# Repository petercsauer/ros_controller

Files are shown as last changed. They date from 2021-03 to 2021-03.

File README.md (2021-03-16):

# ros_controller

## Project Description
The ROS Controller was created as a part of a MSR @ Northwestern winter project. The goal was to create a controller that can be easily customized to help ROS developers debug new applications and help regular robot technicians program new capabilities into existing applications. Please see https://petercsauer.github.io/controller.html for more information.

## Usage Instructions
- Connect the robot and controller to the same network
- export ROS_HOSTNAME=http://raspberrypi.local:11311 (on robot)
- export ROS_IP=raspberrypi.local (on robot)
- roslaunch control control.launch (on controller)
- run any node to be tested on the robot

## Software
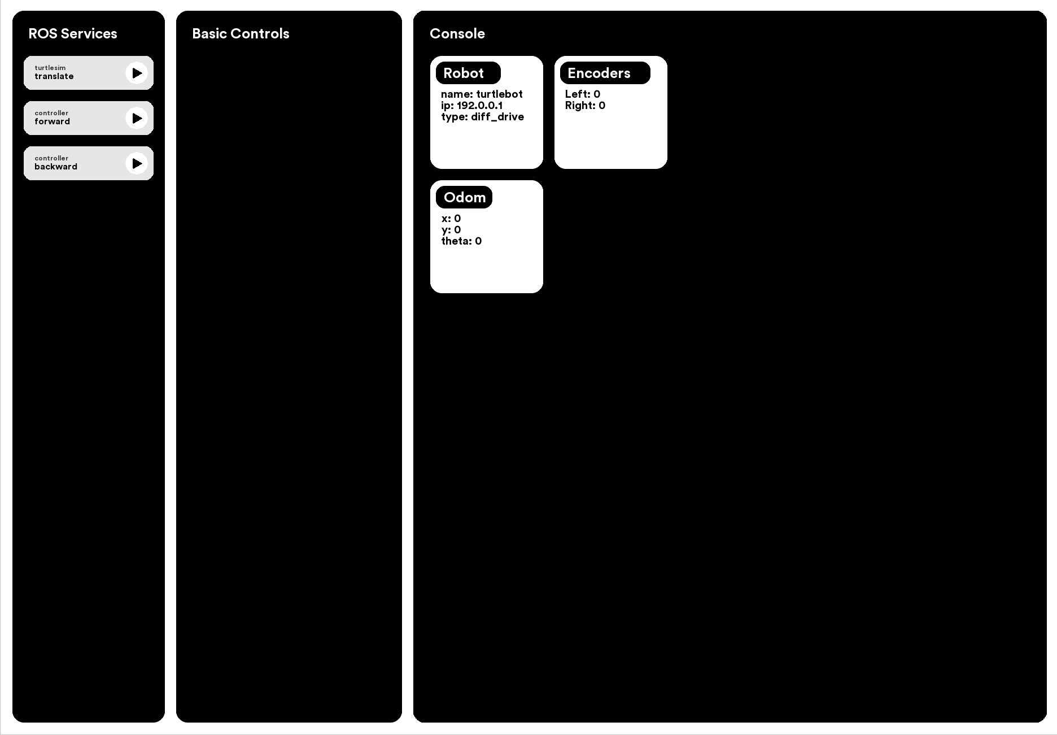
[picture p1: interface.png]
Interface

### Modes of Usage
##### Mouse Control Mode
- In this mode, the left joystick controls the mouse on the raspberry pi in the controller. 
- This can be useful to select functions and run programs on raspberry OS.
- Can switch between mouse control and velocity control modes by holding down the joystick button for 2 seconds.
- Video Demo: https://drive.google.com/file/d/1apWOIeSkuBDc_xTBUmET32rqAUC1X6jY/view?usp=sharing

##### Joystick Control Mode 
- In this mode, the left joystick controls the menu selection options in the interface
- This can be used to press the menu buttons in the application and run services or remote options.
- Can switch between joystick control and velocity control modes by holding down the joystick button for 2 seconds.

##### Velocity Control Mode
- In this mode, the left joystick sends cmd_vel commands to any connected robot
- This can be useful to drive around a diff drive style of robot.
- In this mode, movement left to right publishes to twist.angular.z and up and down movement publishes to twist.linear.x
- Video Demo: https://drive.google.com/file/d/1Vq2hrRpSAihLlSR3H_R1zQseN4hwDoo5/view?usp=sharing

##### Mouse and Keyboard Control
- The controller comes with a wireless mouse and keyboard attatched, so the developer can utilize all of the raspbian os.
- In this mode, the controller becomes a full linux computer, using the eink display as a full display.
- Video Demo: https://drive.google.com/file/d/1e-eE9lNR6LbbHdcuiJWl0FAsSrEUFRB0/view?usp=sharing

##### Info Modules
- Info modules have been created to allow the developer to easily display useful data from the robot.
- In this example, the robots pose, and encoder data is published here as well as some useful data about the robot.
- Video Demo: https://drive.google.com/file/d/1NOoGeiinw6MxqIVGJ60zSW3B7ncj2-ec/view?usp=sharing

##### Service Modules
- Service modules have been created to allow the developer to easily test different services offered by the robot.
- Developers can click the play button next to a service option to run that service with an autocompleted command (\t).
- Developers can click the main section of the service module to input their own command to run.

### Configurability
##### Info Modules
- Info modules can be configured in the modules.yaml file. 
- Info modules can be removed or added depending on the setting in that file and the usage case of the developer

##### Basic Remote
- Action buttons can also be added through the modules.yaml file.
- Each button has a publisher associated with it, and can publish a specific message which is configured by the developer in the modules.yaml file

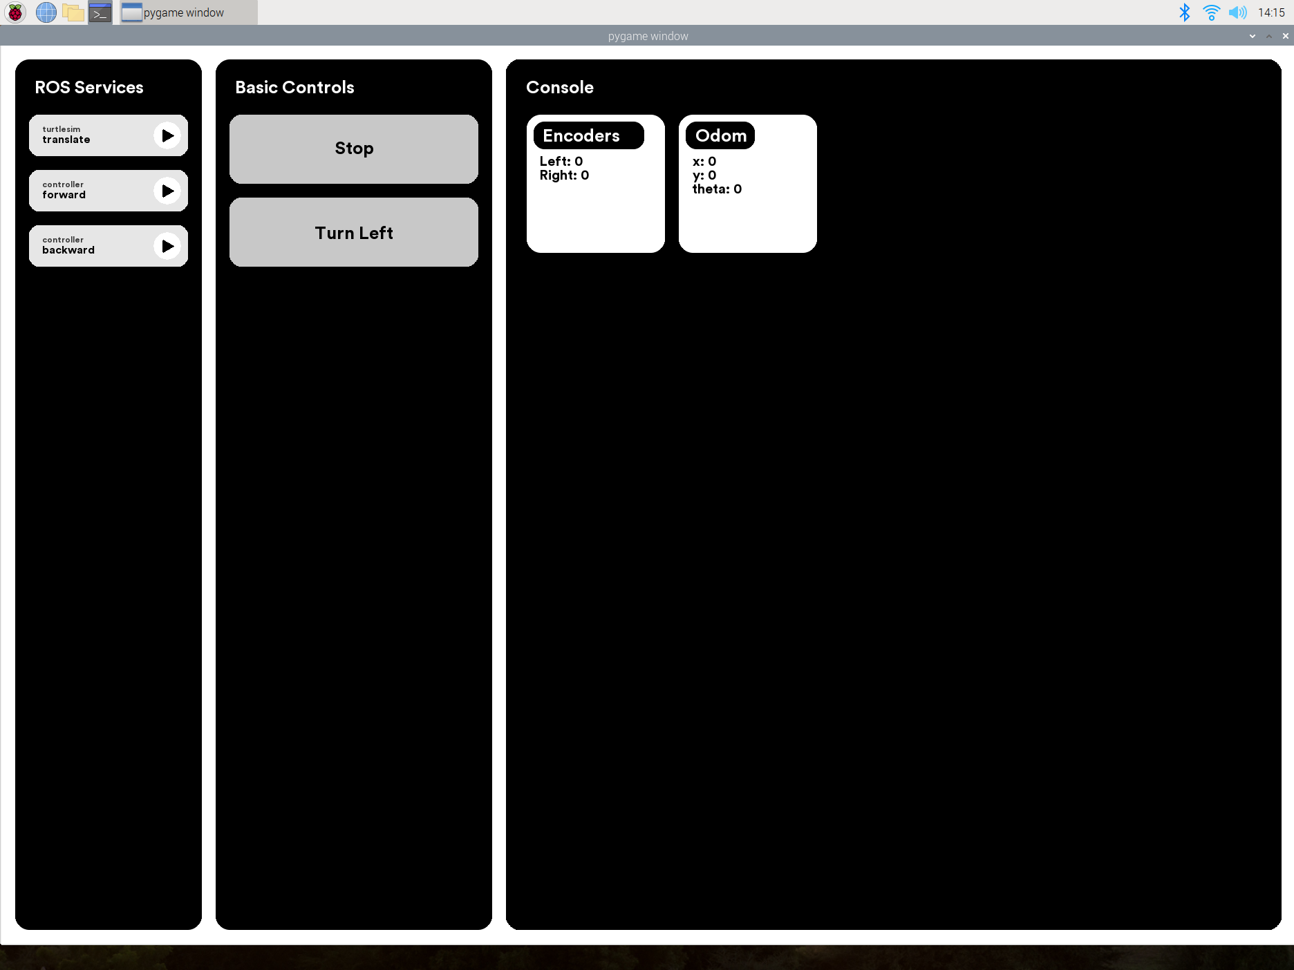
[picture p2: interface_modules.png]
Interface Modules Interface


### Nodes
##### Interface
- the interface node subscribes to useful rostopics (such as the robots pose or joint states)
- it displays this information using a GUI designed by me from scratch using pygame. 

##### Controller
- the controller node publishes cmd_vels from the left joystick when in Velocity control mode.
- it also allows the user to control the mouse using pynput when in Mouse control mode.
- the controller node also publishes an array of buttons and which one is selected currently by the joystick

## Hardware
### BOM
##### Electronics
- Microcontroller: RaspberryPI 4 (4GB RAM) (
- Display Driver: Waveshare HDMI Interface (https://www.waveshare.com/7.8inch-hdmi-e-paper.htm)
- Joysticks: Sparkfun Qwiic Joystick (https://www.sparkfun.com/products/15168)
- Display: Waveshare 7.8" Eink Display (https://www.waveshare.com/7.8inch-hdmi-e-paper.htm)

##### Cables
- USB C Extension: https://www.digikey.com/en/products/detail/sparkfun-electronics/CAB-15455/10819694
- HDMI (Mini to Micro): https://www.amazon.com/Nanosecond-Extreme-Slim-Mini-Cable/dp/B01NC2X1DM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
- Raspberry PI Power Supply: https://vilros.com/collections/official-raspberry-pi-accessories/products/official-raspberry-pi-foundation-power-supply-for-raspberry-pi-4-us-white-ul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 

##### Construction Materials
- Black 1/4" Acrylic (Laser Cut)
- 2" 10-32 Machine Screws (Black Oxide) (4X)
- 10-32 Machine Nuts (4x)
- Double Sided 3M Foam Tape

### CAD
##### CAD Files
- The CAD files for this project are located in the Hardware directory of this repository
- Hardware/Assemblies/FullAssembly.sldasm: The Full controller assembly
- Hardware/Assemblies/FrontAssembly.sldasm: The assembly of the front screen and joystick controllers
- Hardware/Assemblies/BackAssembly.sldasm: The assembly of the RPi4 and HDMI Interface boards
- Hardware/DXF: The DXF files for the different laser cut panels that make up the casing

##### Renders
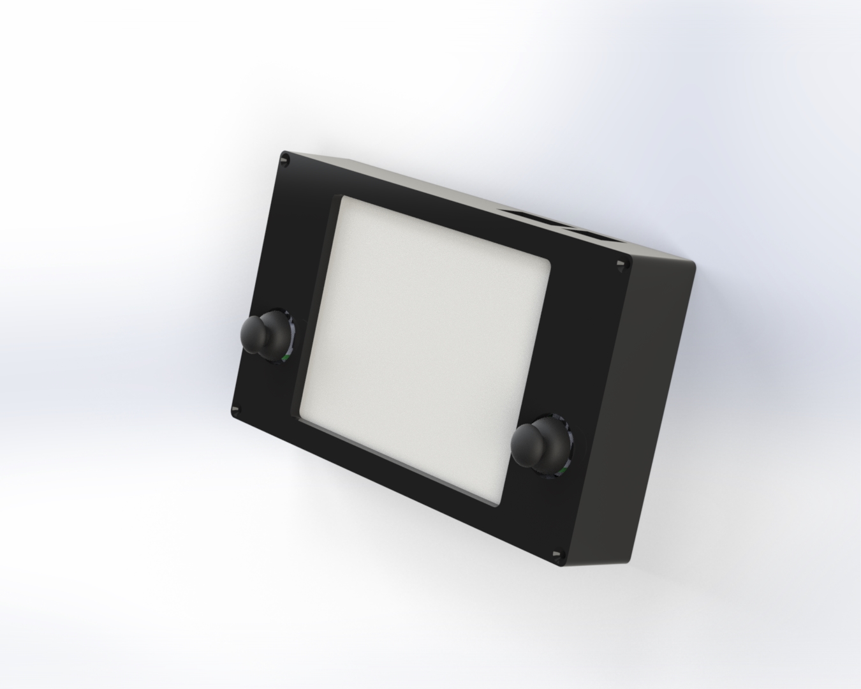
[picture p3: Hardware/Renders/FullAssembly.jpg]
Full Assembly
- Full Assembly 
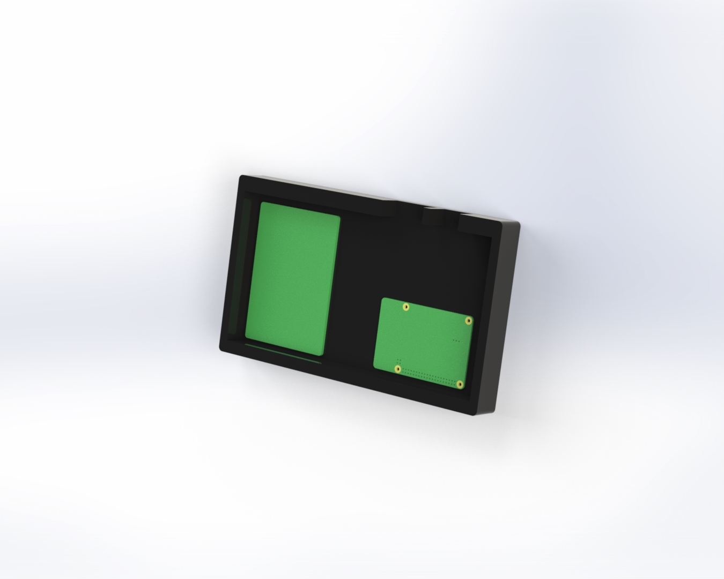
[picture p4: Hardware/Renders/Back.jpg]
Back Assembly
- Back Assembly 
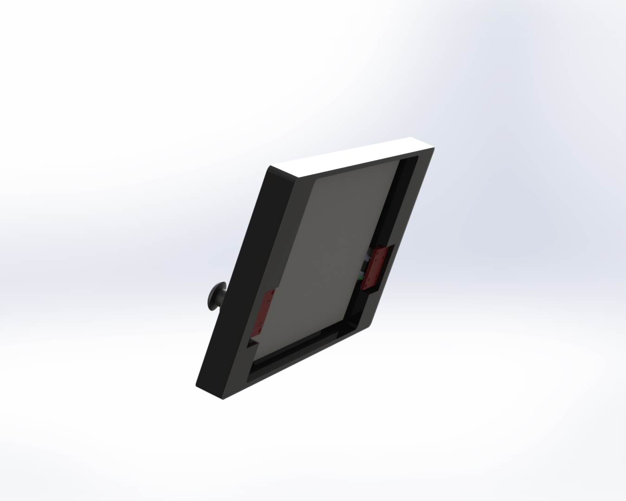
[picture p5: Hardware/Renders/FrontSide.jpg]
Front Assembly
- Front Assembly (Side View) 
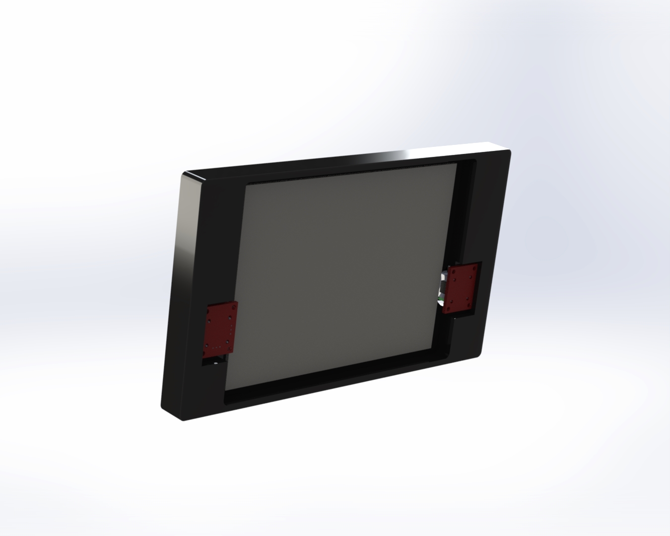
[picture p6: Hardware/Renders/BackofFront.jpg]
Front Assembly
- Front Assembly (Back View)

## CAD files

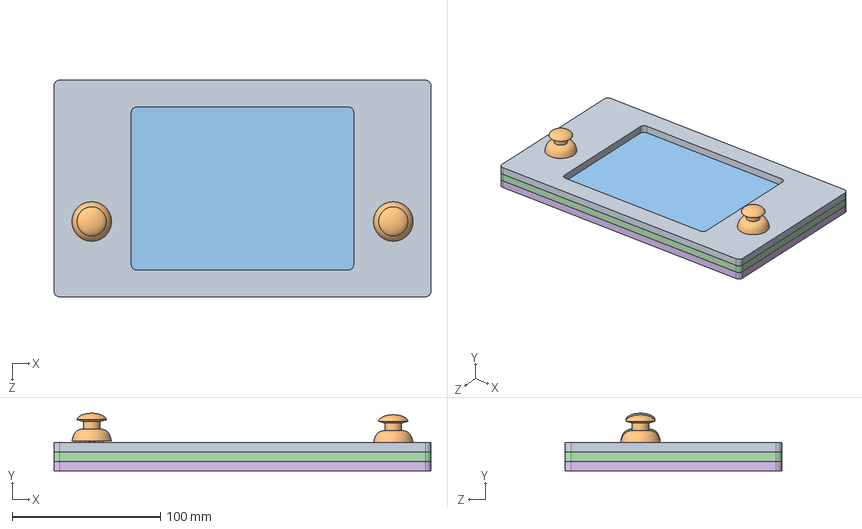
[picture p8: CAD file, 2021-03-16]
Hardware/Assemblies/Front Asembly.SLDASM
254.0 x 38.9 x 146.1 mm
front panel
Waveshare 7.8 Eink
middle panel 1
joystick-breakout x 2
middle panel 2

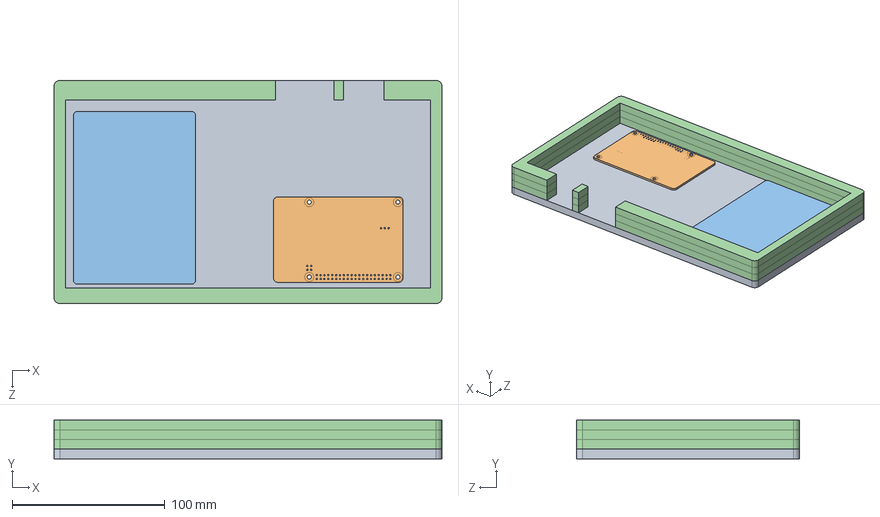
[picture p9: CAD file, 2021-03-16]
Hardware/Assemblies/Back Assemby.SLDASM
254.0 x 25.4 x 146.1 mm
back panel
PCB, RPi4ModelB
HDMI Driver Board
middle panel back 1 x 3

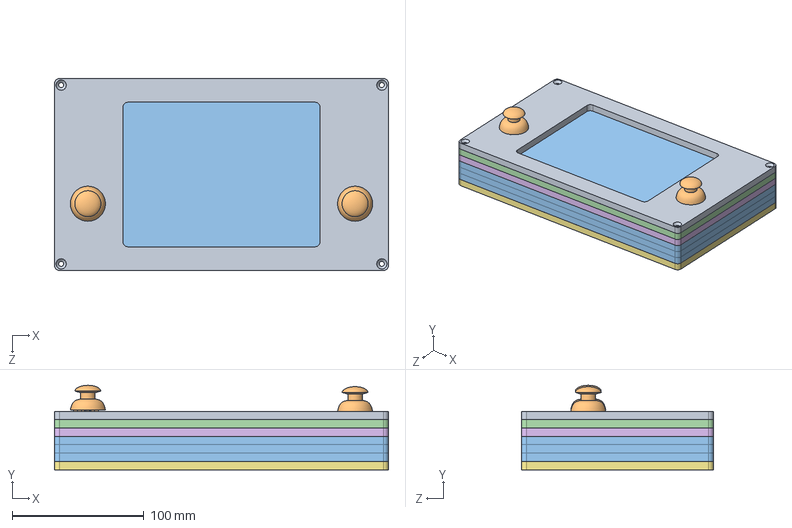
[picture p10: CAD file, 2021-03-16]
Hardware/Assemblies/Full Asembly.SLDASM
254.0 x 64.3 x 146.1 mm
front panel
Waveshare 7.8 Eink
middle panel 1
joystick-breakout x 2
middle panel 2
back panel
PCB, RPi4ModelB
HDMI Driver Board
SAINSMART NANO V3.0 ATMEGA328
middle panel back 1 x 3

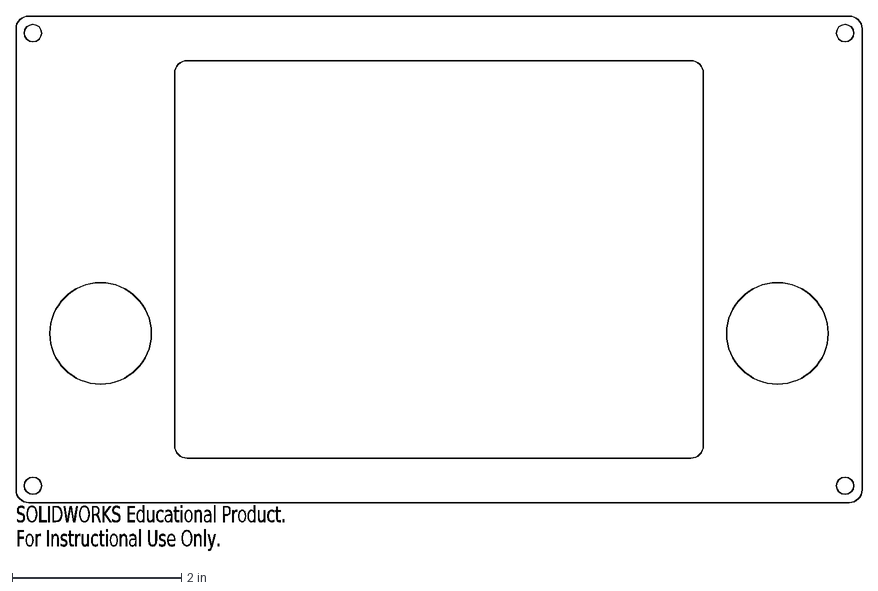
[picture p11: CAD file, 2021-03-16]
Hardware/DXF/front panel.DXF
SOLIDWORKS Educational Product.
For Instructional Use Only.

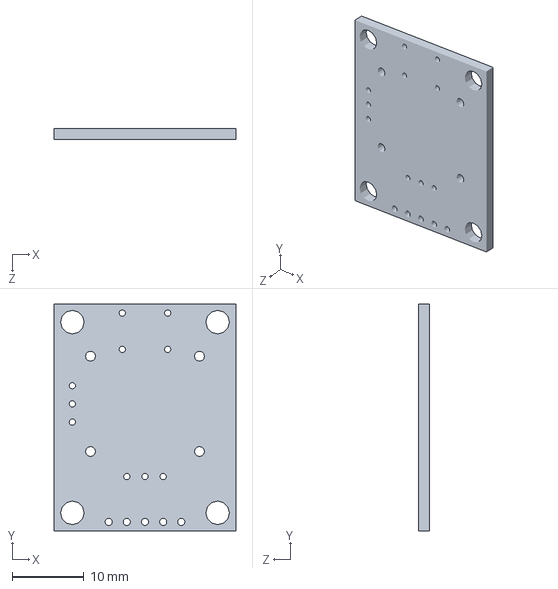
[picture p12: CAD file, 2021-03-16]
Hardware/Electronics/joystick-breakout-v12.SLDPRT
25.4 x 31.8 x 1.60 mm

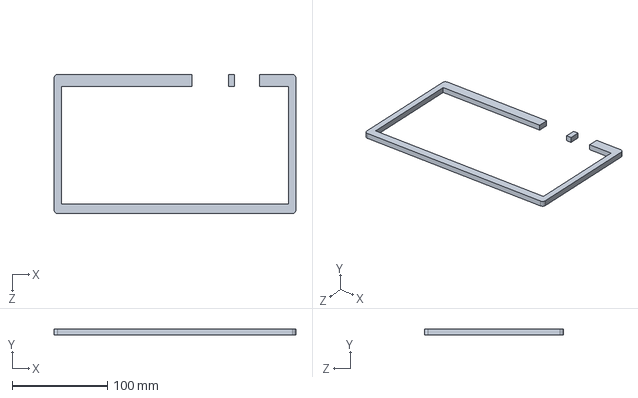
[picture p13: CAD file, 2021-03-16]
Hardware/Panels/middle panel back 1.SLDPRT
254.0 x 6.35 x 146.1 mm

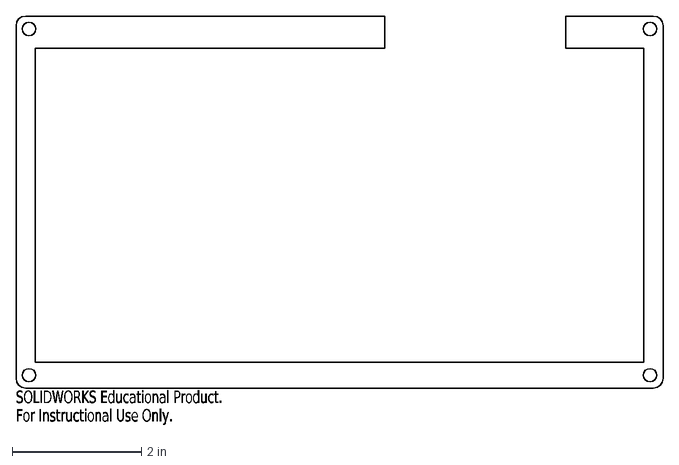
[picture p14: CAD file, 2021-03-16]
Hardware/DXF/middle panel back 1.DXF
SOLIDWORKS Educational Product.
For Instructional Use Only.

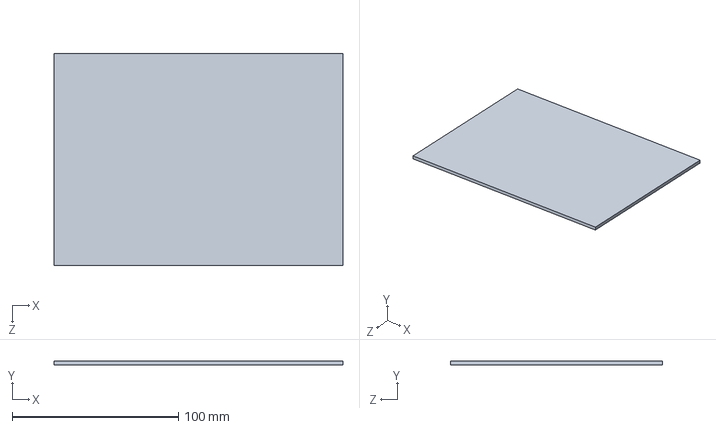
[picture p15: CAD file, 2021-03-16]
Hardware/Electronics/Waveshare 7.8 Eink.SLDPRT
173.8 x 2.54 x 127.6 mm

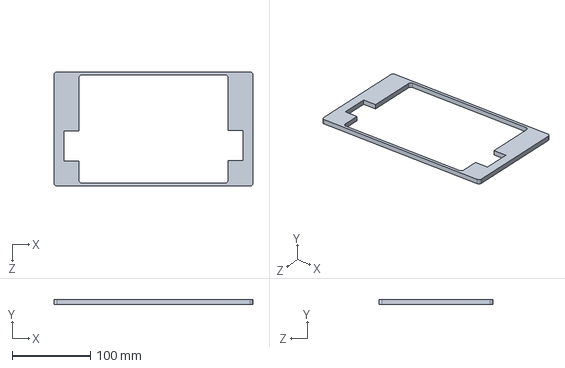
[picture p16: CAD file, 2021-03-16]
Hardware/Panels/middle panel 2.SLDPRT
254.0 x 6.35 x 146.1 mm

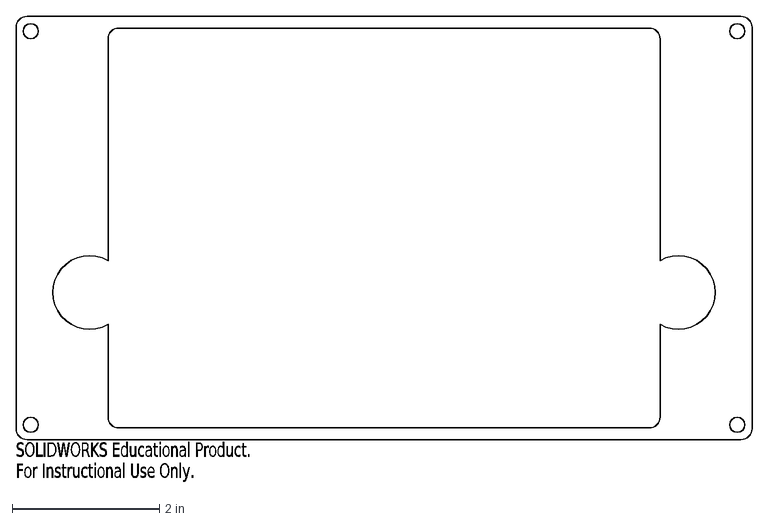
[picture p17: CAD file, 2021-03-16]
Hardware/DXF/middle panel 1.DXF
SOLIDWORKS Educational Product.
For Instructional Use Only.

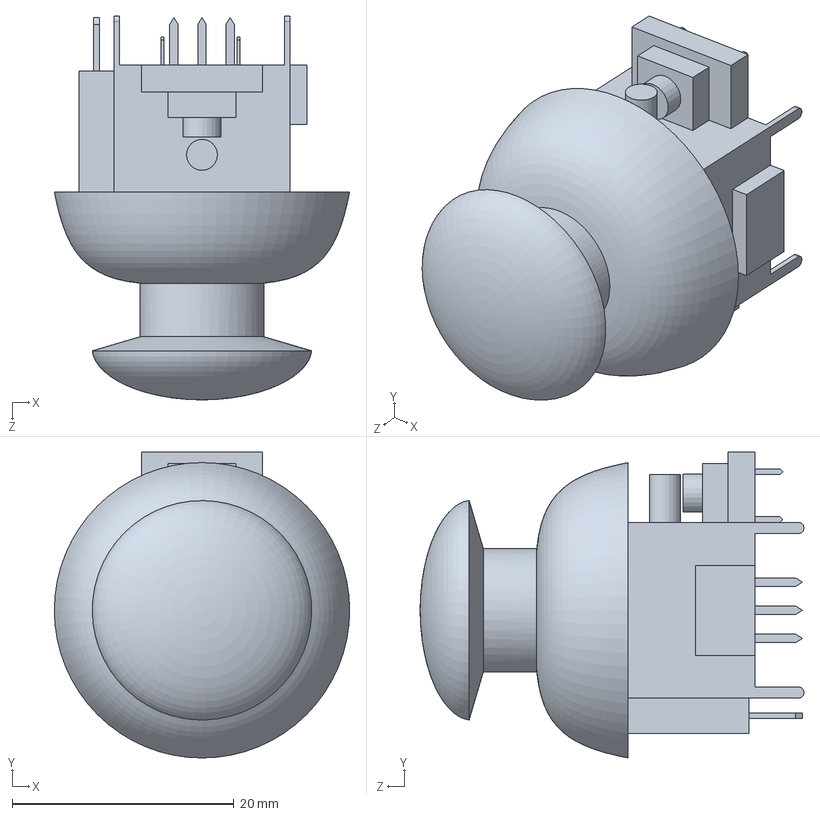
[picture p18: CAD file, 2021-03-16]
Hardware/Electronics/9032.SLDPRT
26.7 x 27.6 x 34.7 mm

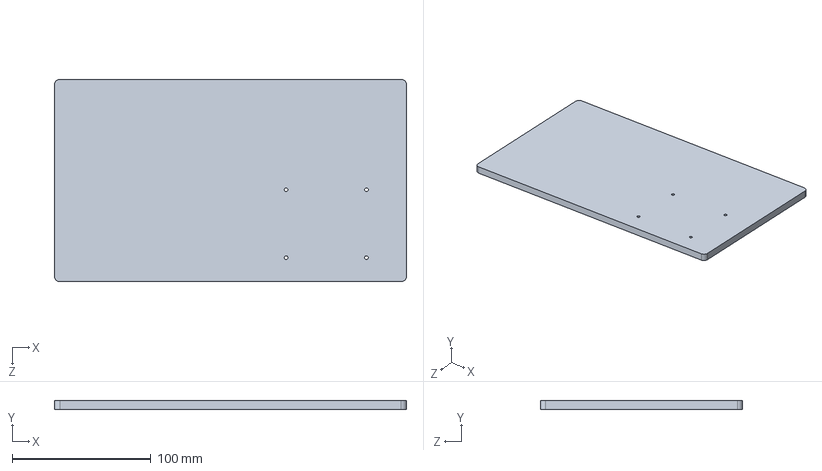
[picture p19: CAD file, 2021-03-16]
Hardware/Panels/back panel.SLDPRT
254.0 x 6.35 x 146.1 mm

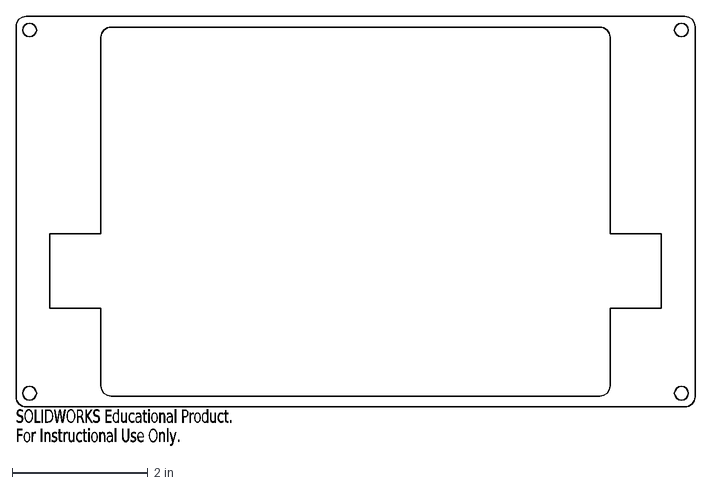
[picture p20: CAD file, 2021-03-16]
Hardware/DXF/middle panel 2.DXF
SOLIDWORKS Educational Product.
For Instructional Use Only.

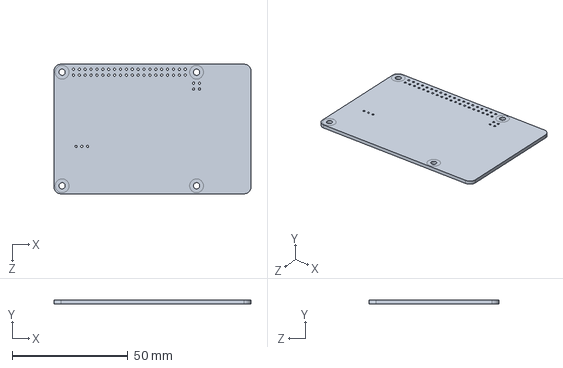
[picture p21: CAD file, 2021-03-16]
Hardware/Electronics/PCB, RPi4ModelB.SLDPRT
85.0 x 1.60 x 56.0 mm

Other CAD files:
Hardware/Panels/middle panel 1.SLDPRT
Hardware/Electronics/HDMI Driver Board.SLDPRT
Hardware/Panels/front panel.SLDPRT
Hardware/Electronics/joystick-breakout.SLDPRT
Hardware/Electronics/SAINSMART NANO V3.0 ATMEGA328.SLDPRT
